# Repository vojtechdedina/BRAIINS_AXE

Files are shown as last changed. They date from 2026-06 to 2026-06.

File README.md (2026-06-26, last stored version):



**DoubleQ Rev2.2 **

Alternative PCB design to fit another cooler for an open PCB. 



Highlights in comparison to the "standard" NerdOCTAXE:
- runs far more silent
- lower temps on asics and buck
- open PCB-design

The NerdOCTAXEγ runs with a modified version of the AxeOS: [ESP-Miner-NerdQAxe+](https://github.com/shufps/ESP-Miner-NerdQAxePlus) (Releases for NerdOCTAXE-Gamma)

-------------------------------

# Build

**DISCLAIMER:** This device is an *highly advanced* build and partly WIP. To get 8 Asics and the voltage regulator soldered properly *can* be very hard and frustrating if you are not used to soldering Asics or soldering in general. Using that amount of power, this device isn't a toy and you should know what you are doing - stay safe! Also this device is not intended or designed to run overclocked.

**PCB:** For example with the JLC Plugin for Kicad you can export the files out of Kicad to order directly from JLCPCB or any other PCB-Manufacturer. I tested my prototype with 1oz on inner and outer layers... working nice :) If anyone is testing or 2/1oz please let me know of the results you are seeing!

**BOM:** You can directly upload the .csv in this repo to Digikey. You will have to order the Lilygo T-Display S3 and the XT60PW-M seperately 

**HEATSINKS:** For this build I used two Thermalright AXP90-X53. For cooling the CSDs I "tinkered" on a custom heatsink with a 150x10mm aluminum rod and some fins, which I cut off another heatsink :) But its possible to just use 4x smaller heatsink directly on the CSDs



Misc
====
If you like this project and want to support future work, feel free to donate to:
**`bc1q0ctaxeha3lpsaaz7kpjulflw2d9p66fhkp48dk`**

or related projects without which this project would not have been possible for me:

[Nerdaxe](https://github.com/BitMaker-hub/NerdAxeUltra)

[NerdQAxe+](https://github.com/shufps/qaxe)

[OSMU](https://osmu.wiki/)

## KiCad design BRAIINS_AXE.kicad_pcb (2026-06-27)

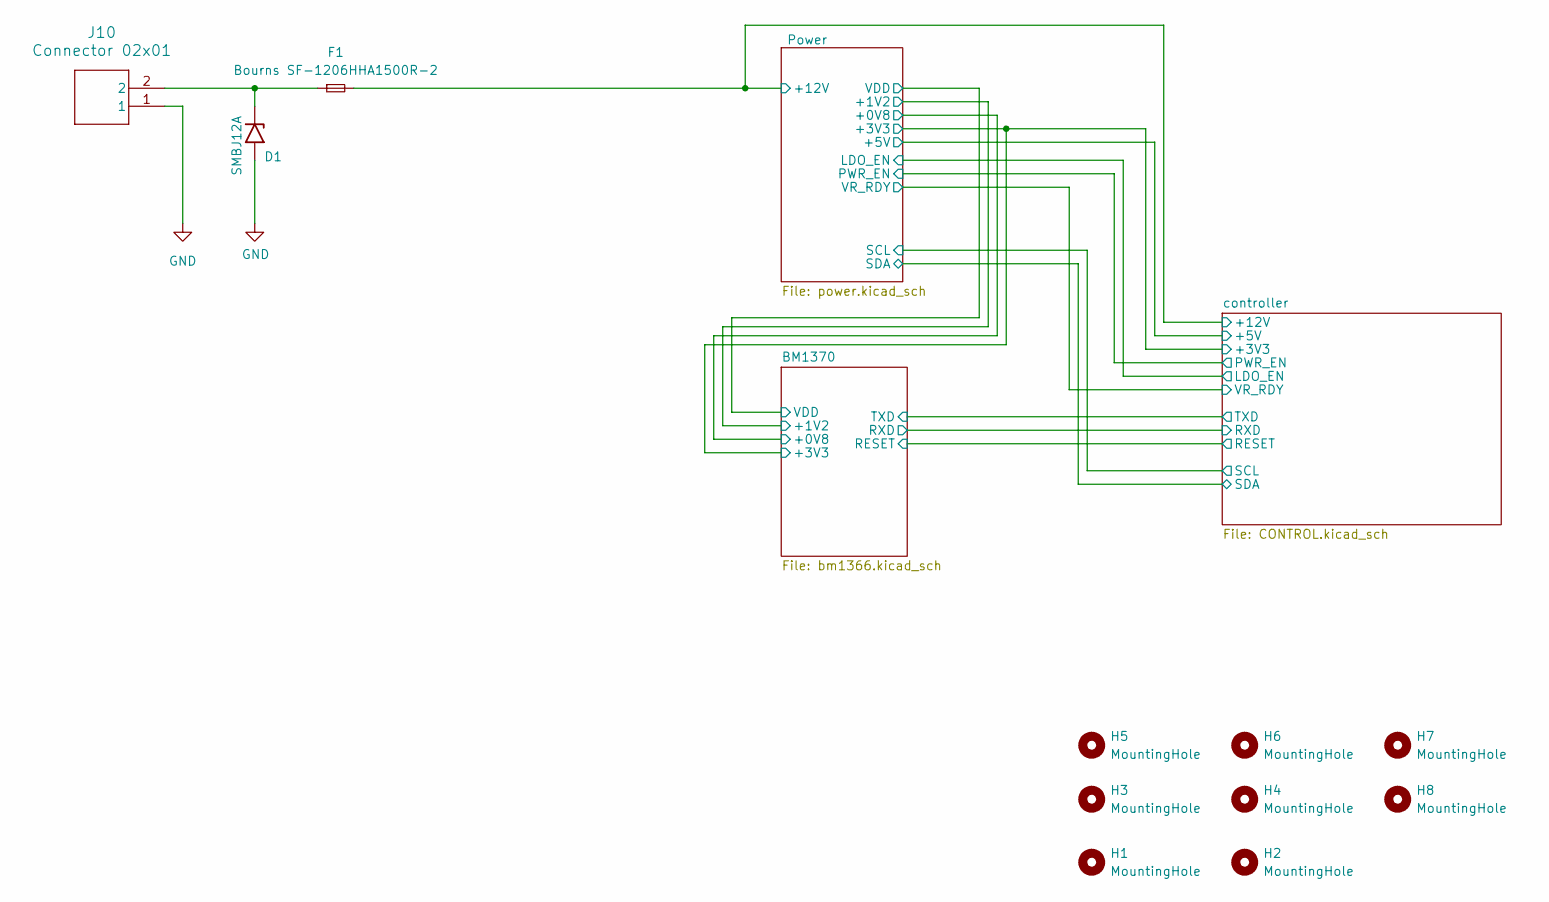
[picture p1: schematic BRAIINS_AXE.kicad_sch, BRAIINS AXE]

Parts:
D1: SMBJ12A; D_SMB
F1: Bourns SF-1206HHA1500R-2; Fuse_1210_3225Metric
H1, H2, H3, H4, H5, H6, H7, H8: MountingHole; MountingHole_3.2mm_M3_Pad_Via
J10: Connector 02x01; AMASS_XT60PW-M_1x02_P7.20mm_Horizontal

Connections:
+12V: F1.2; also elsewhere on the board
GND: D1.2 (A2), J10.1; also elsewhere on the board
unnamed: D1.1 (A1), F1.1, J10.2

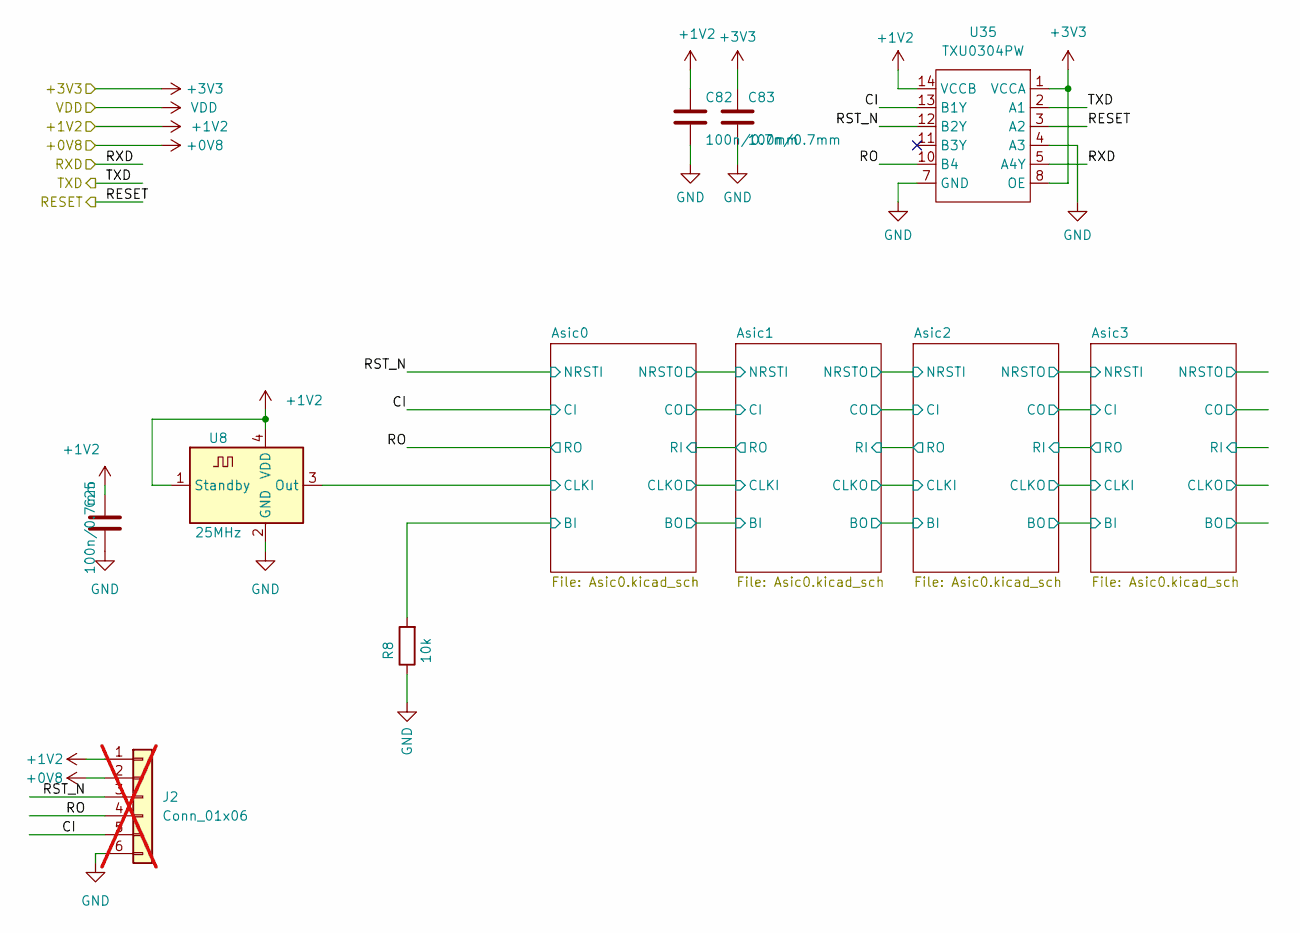
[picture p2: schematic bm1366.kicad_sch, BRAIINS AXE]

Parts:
C25, C82, C83: 100n/0.7mm; C_0805_2012Metric
J2: Conn_01x06; PinHeader_1x06_P1.27mm_Vertical; not fitted
R8: 10k; R_0805_2012Metric
U8: 25MHz; Oscillator_SMD_EuroQuartz_XO32-4Pin_3.2x2.5mm
U35: TXU0304PW; TSSOP-14-1EP_4.4x5mm_P0.65mm

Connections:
+0V8: J2.2; also elsewhere on the board
+1V2: C25.1, C82.1, J2.1, U8.1 (Standby), U8.4 (VDD), U35.14 (VCCB); also elsewhere on the board
+3V3: C83.1, U35.1 (VCCA), U35.8 (OE); also elsewhere on the board
/BM1370/Asic0/BI: R8.2; also elsewhere on the board
/BM1370/Asic0/CLKI: U8.3 (Out); also elsewhere on the board
/BM1370/CI: J2.5, U35.13 (B1Y); also elsewhere on the board
/BM1370/RESET: U35.3 (A2); also elsewhere on the board
/BM1370/RO: J2.4, U35.10 (B4); also elsewhere on the board
/BM1370/RST_N: J2.3, U35.12 (B2Y); also elsewhere on the board
/BM1370/RXD: U35.5 (A4Y); also elsewhere on the board
/BM1370/TXD: U35.2 (A1); also elsewhere on the board
GND: C25.2, C82.2, C83.2, J2.6, R8.1, U8.2 (GND), U35.4 (A3), U35.7 (GND); also elsewhere on the board

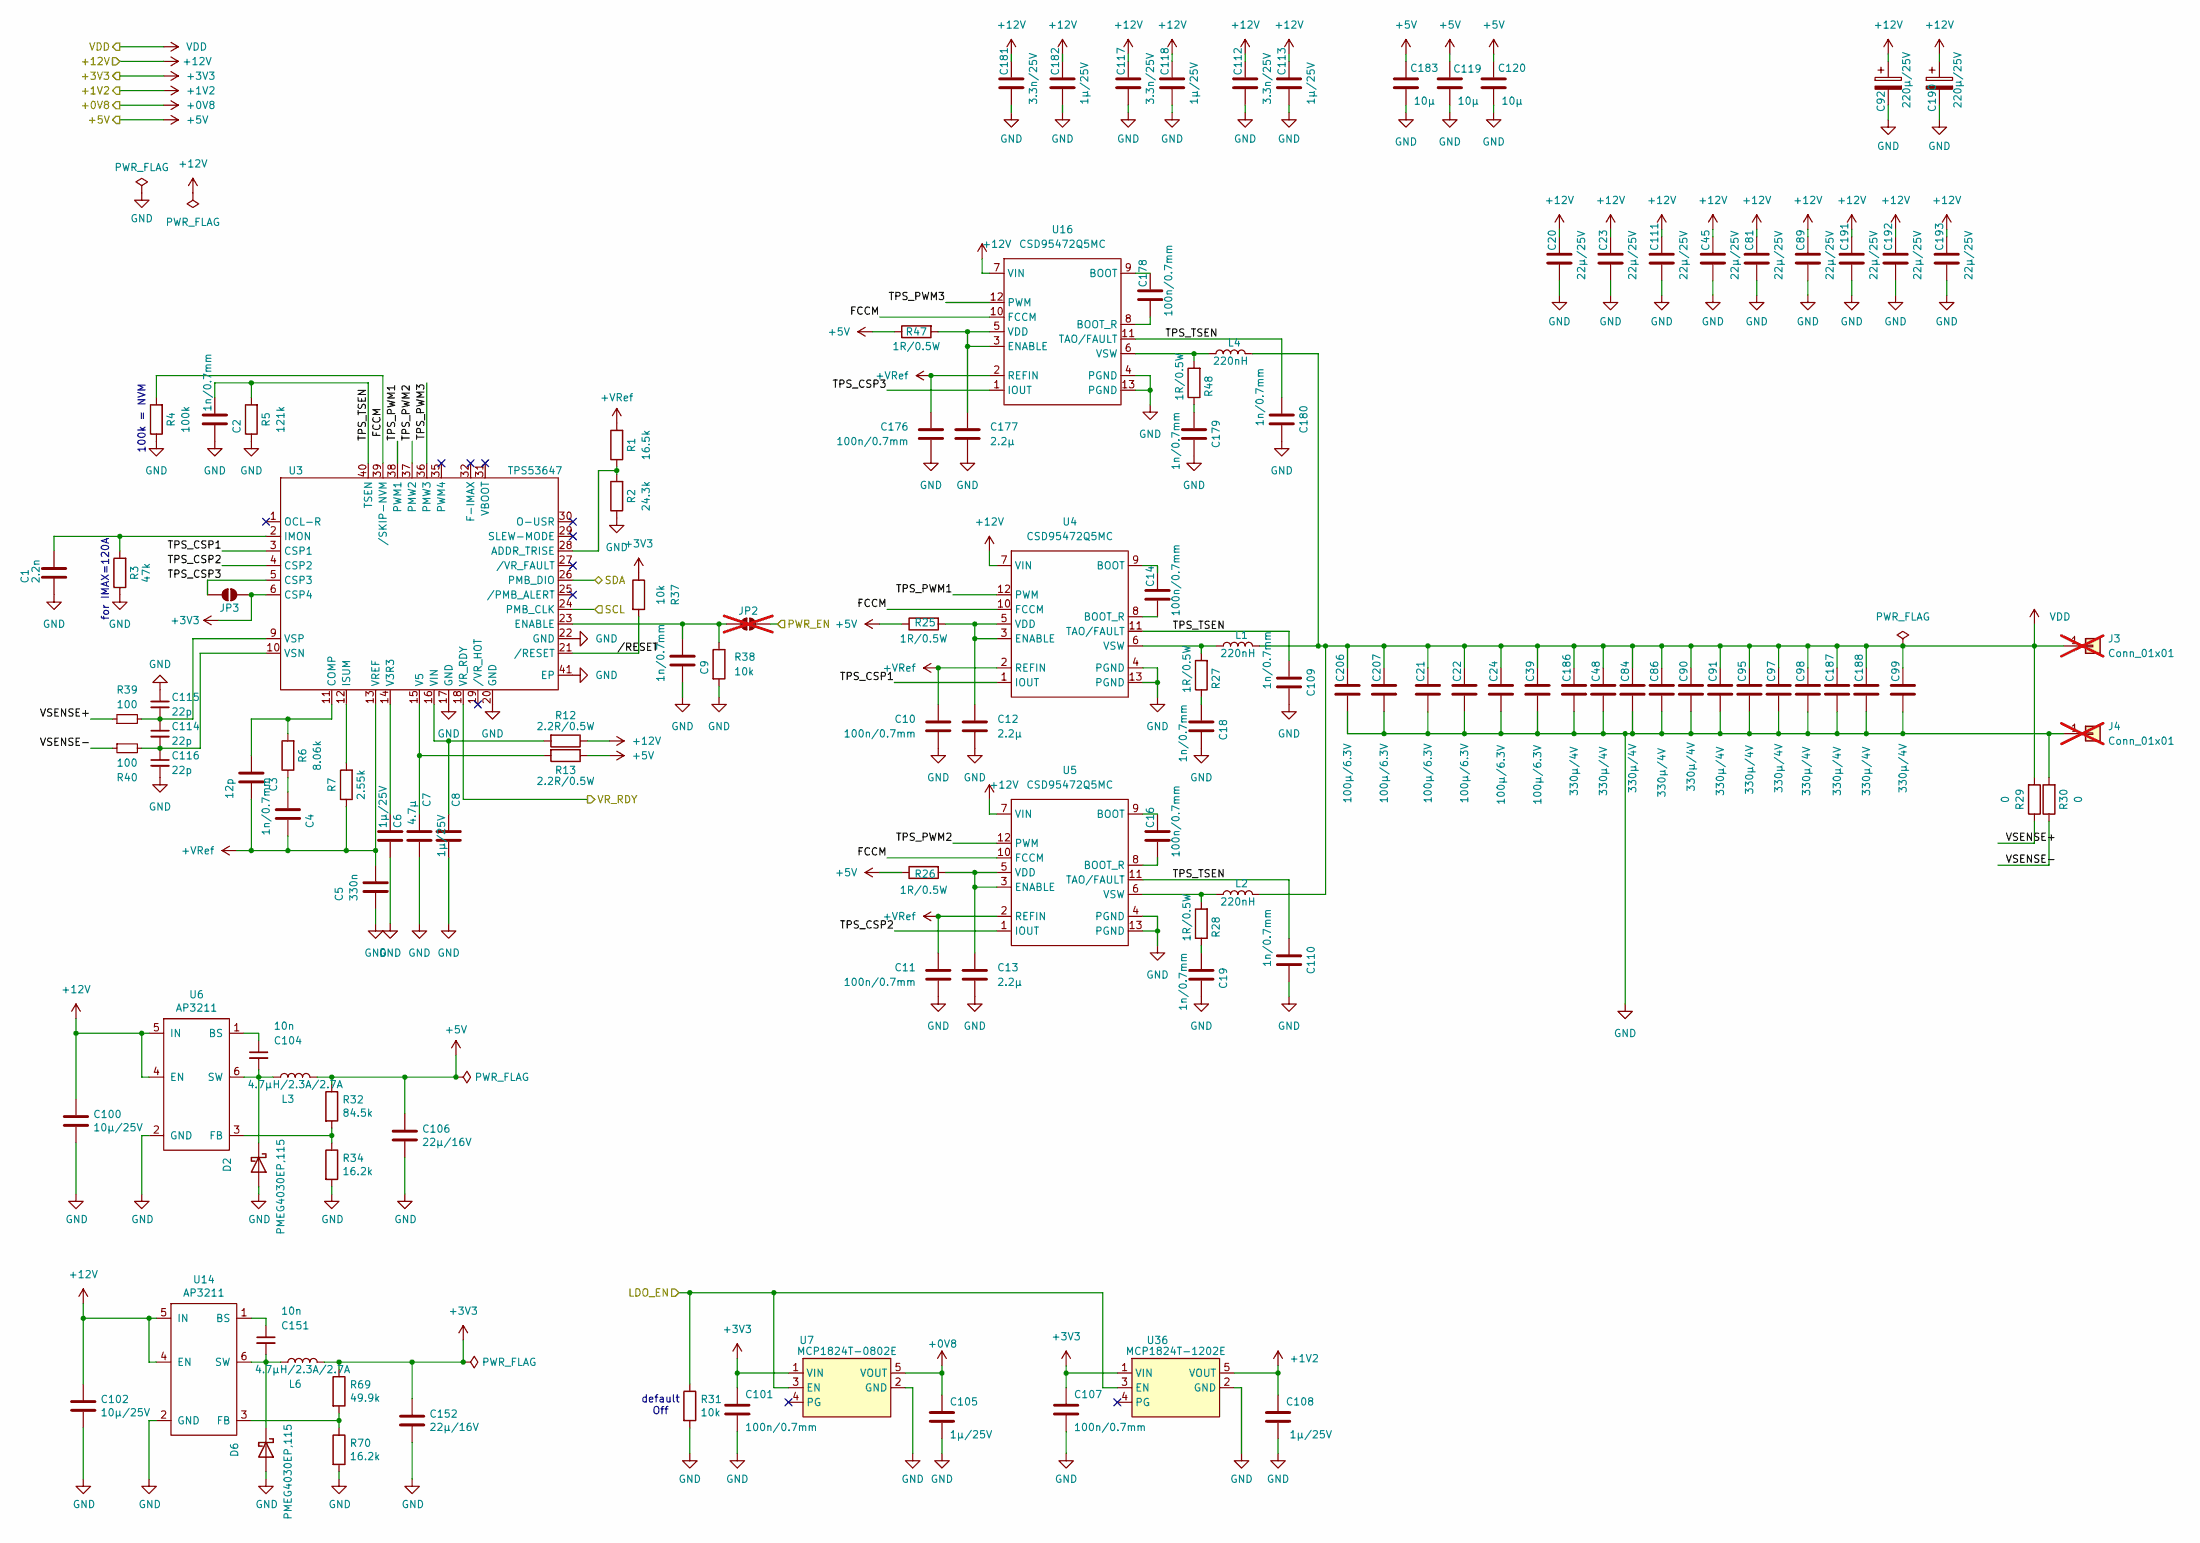
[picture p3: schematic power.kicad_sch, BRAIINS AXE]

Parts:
C1: 2.2n; C_0603_1608Metric
C2, C4, C9: 1n/0.7mm; C_0603_1608Metric
C3: 12p; C_0603_1608Metric
C5: 330n; C_0603_1608Metric
C6, C8, C113, C118, C182: 1µ/25V; C_0603_1608Metric
C7: 4.7µ; C_0603_1608Metric
C10, C11, C14, C16, C176, C178: 100n/0.7mm; C_0603_1608Metric
C12, C13, C177: 2.2µ; C_0603_1608Metric
C18, C19, C109, C110, C179, C180: 1n/0.7mm; C_0805_2012Metric
C20, C23, C45, C81, C89, C111, C191, C192, C193: 22µ/25V; C_1210_3225Metric
C21, C22, C24, C39, C206, C207: 100µ/6.3V; C_1210_3225Metric
C48, C84, C86, C90, C91, C95, C97, C98, C99, C186, C187, C188: 330µ/4V; C_1210_3225Metric
C92, C190: 220µ/25V; CP_Elec_8x10
C100, C102: 10µ/25V; C_0805_2012Metric
C101, C107: 100n/0.7mm; C_0805_2012Metric
C104, C151: 10n; C_0805_2012Metric
C105, C108: 1µ/25V; C_0805_2012Metric
C106, C152: 22µ/16V; C_1206_3216Metric
C112, C117, C181: 3.3n/25V; C_0603_1608Metric
C114, C115, C116: 22p; C_0603_1608Metric
C119, C120, C183: 10µ; C_0805_2012Metric
D2, D6: PMEG4030EP,115; D_SOD-128
J3, J4: Conn_01x01; Wuerth_REDCUBE-THR_WP-THRBU_74650194_THR; not fitted
JP2: SolderJumper_2_Open; SolderJumper-2_P1.3mm_Open_RoundedPad1.0x1.5mm; not fitted
JP3: SolderJumper_2_Open; SolderJumper-2_P1.3mm_Open_RoundedPad1.0x1.5mm
L1, L2, L4: 220nH; IFLR-4031GC-01-8x10
L3, L6: 4.7µH/2.3A/2.7A; L_Taiyo-Yuden_NR-50xx
R1: 16.5k; R_0603_1608Metric
R2: 24.3k; R_0603_1608Metric
R3: 47k; R_0603_1608Metric
R4: 100k; R_0603_1608Metric
R5: 121k; R_0603_1608Metric
R6: 8.06k; R_0603_1608Metric
R7: 2.55k; R_0603_1608Metric
R12, R13: 2.2R/0.5W; R_0805_2012Metric
R25, R26, R27, R28, R47, R48: 1R/0.5W; R_0805_2012Metric
R29, R30: 0; R_0805_2012Metric
R31: 10k; R_0805_2012Metric
R32: 84.5k; R_0603_1608Metric
R34, R70: 16.2k; R_0603_1608Metric
R37, R38: 10k; R_0603_1608Metric
R39, R40: 100; R_0603_1608Metric
R69: 49.9k; R_0603_1608Metric
U3: TPS53647; Texas_RHA0040B_VQFN-40-1EP_6x6mm_P0.5mm_EP4.15x4.15mm_Therm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
U4, U5, U16: CSD95472Q5MC; CSD95472-SON-5x6
U6, U14: AP3211; SOT-23-6
U7: MCP1824T-0802E; SOT-23-5
U36: MCP1824T-1202E; SOT-23-5

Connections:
+0V8: C105.1, U7.5 (VOUT); also elsewhere on the board
+1V2: C108.1, U36.5 (VOUT); also elsewhere on the board
+3V3: C101.1, C107.1, C152.1, JP3.2 (B), L6.2, R37.1, R69.1, U3.6 (CSP4), U7.1 (VIN), U36.1 (VIN); also elsewhere on the board
+5V: C106.1, C119.1, C120.1, C183.1, L3.2, R13.1, R25.1, R26.1, R32.1, R47.1
+12V: C20.1, C23.1, C45.1, C81.1, C89.1, C92.1, C100.1, C102.1, C111.1, C112.1, C113.1, C117.1, C118.1, C181.1, C182.1, C190.1, C191.1, C192.1, C193.1, R12.1, U4.7 (VIN), U5.7 (VIN), U6.4 (EN), U6.5 (IN), U14.4 (EN), U14.5 (IN), U16.7 (VIN); also elsewhere on the board
+VRef: C3.2, C4.2, C5.1, C10.1, C11.1, C176.1, R1.2, R7.1, U3.13 (VREF), U4.2 (REFIN), U5.2 (REFIN), U16.2 (REFIN)
/Power/FCCM: R4.2, U3.39 (/SKIP-NVM), U4.10 (FCCM), U5.10 (FCCM), U16.10 (FCCM)
/Power/LDO_EN: R31.1, U7.3 (EN), U36.3 (EN); also elsewhere on the board
/Power/PWR_EN: JP2.2 (B); also elsewhere on the board
/Power/TPS_CSP1: U3.3 (CSP1), U4.1 (IOUT)
/Power/TPS_CSP2: U3.4 (CSP2), U5.1 (IOUT)
/Power/TPS_CSP3: JP3.1 (A), U3.5 (CSP3), U16.1 (IOUT)
/Power/TPS_PWM1: U3.38 (PWM1), U4.12 (PWM)
/Power/TPS_PWM2: U3.37 (PMW2), U5.12 (PWM)
/Power/TPS_PWM3: U3.36 (PMW3), U16.12 (PWM)
/Power/TPS_TSEN: C2.1, C109.1, C110.1, C180.1, R5.2, U3.40 (TSEN), U4.11 (TAO/FAULT), U5.11 (TAO/FAULT), U16.11 (TAO/FAULT)
/Power/VR_RDY: U3.18 (VR_RDY); also elsewhere on the board
/Power/VSENSE+: R29.1, R39.1
/Power/VSENSE-: R30.1, R40.1
/Power//RESET: R37.2, U3.21 (/RESET)
/controller/SCL: U3.24 (PMB_CLK); also elsewhere on the board
/controller/SDA: U3.26 (PMB_DIO); also elsewhere on the board
GND: C1.2, C2.2, C5.2, C6.2, C7.1, C8.1, C9.2, C10.2, C11.2, C12.2, C13.2, C18.2, C19.2, C20.2, C21.2, C22.2, C23.2, C24.2, C39.2, C45.2, C48.2, C81.2, C84.2, C86.2, C89.2, C90.2, C91.2, C92.2, C95.2, C97.2, C98.2, C99.2, C100.2, C101.2, C102.2, C105.2, C106.2, C107.2, C108.2, C109.2, C110.2, C111.2, C112.2, C113.2, C115.1, C116.2, C117.2, C118.2, C119.2, C120.2, C152.2, C176.2, C177.2, C179.2, C180.2, C181.2, C182.2, C183.2, C186.2, C187.2, C188.2, C190.2, C191.2, C192.2, C193.2, C206.2, C207.2, D2.2 (A), D6.2 (A), J4.1, R2.1, R3.1, R4.1, R5.1, R30.2, R31.2, R34.2, R38.2, R70.2, U3.17 (GND), U3.20 (GND), U3.22 (GND), U3.41 (EP), U4.4 (PGND), U4.13 (PGND), U5.4 (PGND), U5.13 (PGND), U6.2 (GND), U7.2 (GND), U14.2 (GND), U16.4 (PGND), U16.13 (PGND), U36.2 (GND); also elsewhere on the board
unnamed: C4.1, R6.1
unnamed: C18.1, R27.1
unnamed: C19.1, R28.1
unnamed: C179.1, R48.1
unnamed: C104.2, D2.1 (K), L3.1, U6.6 (SW)
unnamed: C151.2, D6.1 (K), L6.1, U14.6 (SW)
unnamed: C9.1, JP2.1 (A), R38.1, U3.23 (ENABLE)
unnamed: R1.1, R2.2, U3.28 (ADDR_TRISE)
unnamed: C3.1, R6.2, U3.11 (COMP)
unnamed: C1.1, R3.2, U3.2 (IMON)
unnamed: R7.2, U3.12 (ISUM)
unnamed: C6.1, U3.14 (V3R3)
unnamed: C7.2, R13.2, U3.15 (V5)
unnamed: C8.2, R12.2, U3.16 (VIN)
unnamed: C114.2, C116.1, R40.2, U3.10 (VSN)
unnamed: C114.1, C115.2, R39.2, U3.9 (VSP)
unnamed: C14.1, U4.9 (BOOT)
unnamed: C14.2, U4.8 (BOOT_R)
unnamed: C12.1, R25.2, U4.3 (ENABLE), U4.5 (VDD)
unnamed: L1.1, R27.2, U4.6 (VSW)
unnamed: C16.1, U5.9 (BOOT)
unnamed: C16.2, U5.8 (BOOT_R)
unnamed: C13.1, R26.2, U5.3 (ENABLE), U5.5 (VDD)
unnamed: L2.1, R28.2, U5.6 (VSW)
unnamed: C104.1, U6.1 (BS)
unnamed: R32.2, R34.1, U6.3 (FB)
unnamed: C151.1, U14.1 (BS)
unnamed: R69.2, R70.1, U14.3 (FB)
unnamed: C178.1, U16.9 (BOOT)
unnamed: C178.2, U16.8 (BOOT_R)
unnamed: C177.1, R47.2, U16.3 (ENABLE), U16.5 (VDD)
unnamed: L4.1, R48.2, U16.6 (VSW)
VDD: C21.1, C22.1, C24.1, C39.1, C48.1, C84.1, C86.1, C90.1, C91.1, C95.1, C97.1, C98.1, C99.1, C186.1, C187.1, C188.1, C206.1, C207.1, J3.1, L1.2, L2.2, L4.2, R29.2; also elsewhere on the board

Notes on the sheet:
default Off
for IMAX=120A
100k = NVM

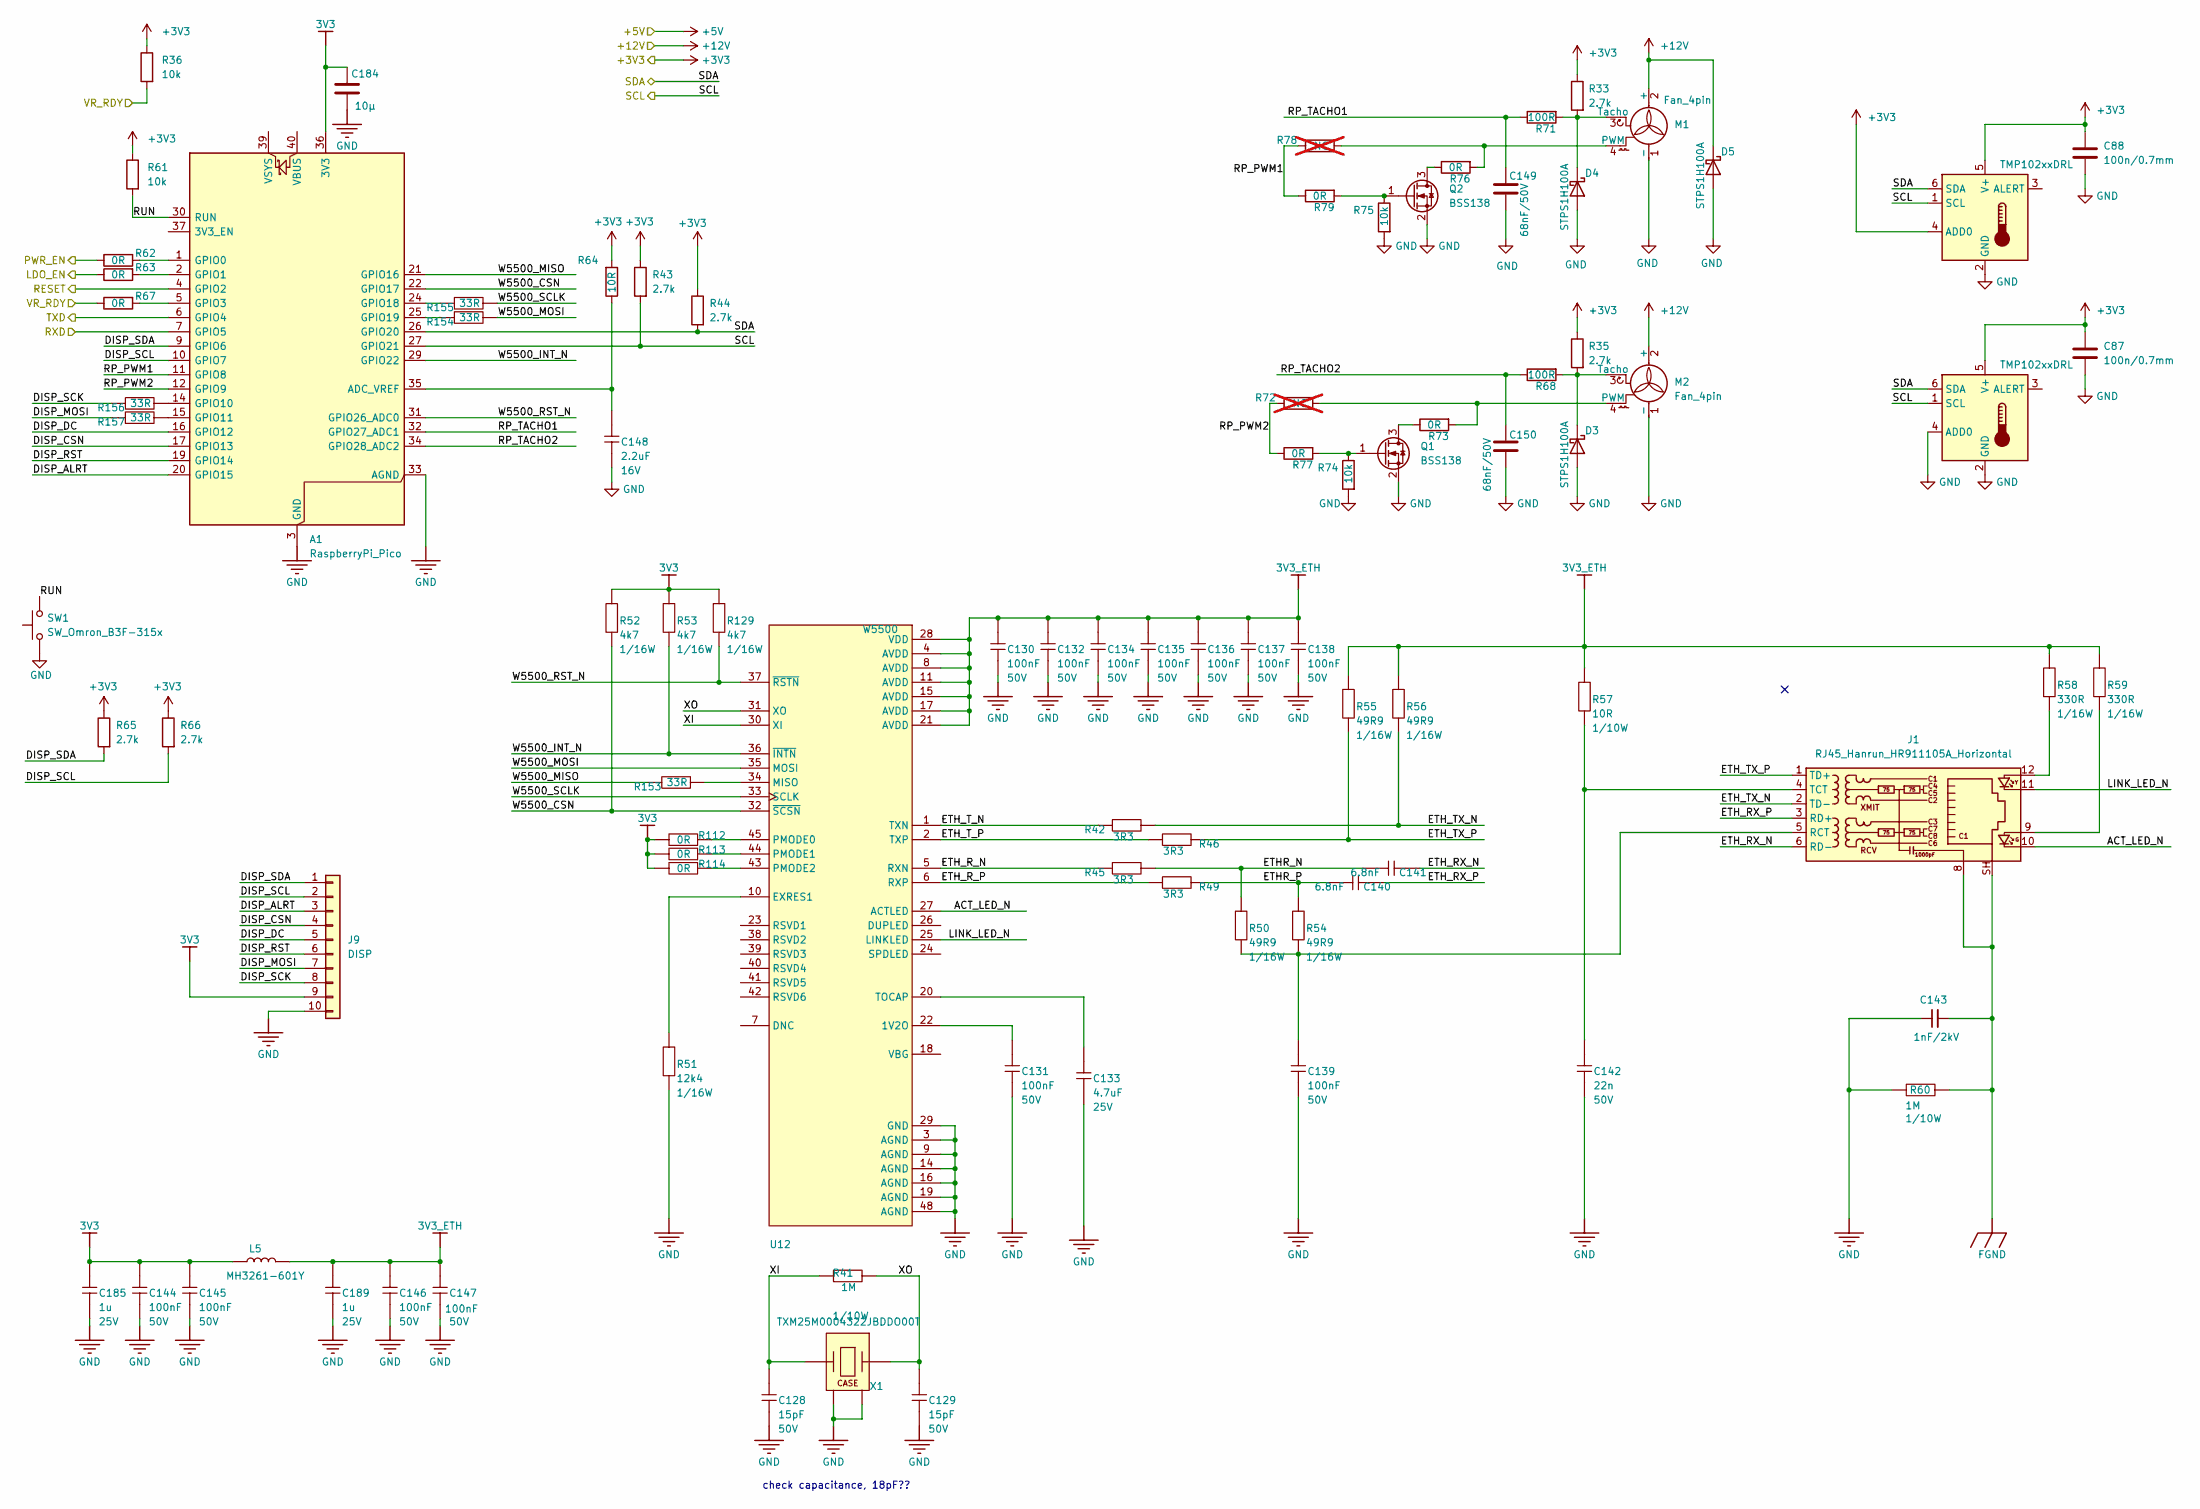
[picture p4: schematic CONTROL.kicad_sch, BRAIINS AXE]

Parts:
A1: RaspberryPi_Pico; RaspberryPi_Pico_Common_Unspecified
C87, C88: 100n/0.7mm; C_0603_1608Metric
C128, C129: 15pF; C_0603_1608Metric; VOLTAGE_RATING 50V; TOLERANCE 1%; PART_TYPE Capacitor
C130, C131, C132, C134, C135, C136, C137, C138, C139, C144, C145, C146, C147: 100nF; C_0603_1608Metric; VOLTAGE_RATING 50V; TOLERANCE 10%; PART_TYPE Capacitor
C133: 4.7uF; C_0603_1608Metric; VOLTAGE_RATING 25V; TOLERANCE 10%; PART_TYPE Capacitor
C140, C141: 6.8nF; C_0603_1608Metric; VOLTAGE_RATING 50V; TOLERANCE 10%; PART_TYPE Capacitor
C142: 22n; C_0603_1608Metric; VOLTAGE_RATING 50V; TOLERANCE 10%; PART_TYPE Capacitor
C143: 1nF/2kV; C_1206_3216Metric
C148: 2.2uF; C_0603_1608Metric; VOLTAGE_RATING 16V; TOLERANCE 10%; PART_TYPE Capacitor
C149, C150: 68nF/50V; C_0603_1608Metric
C184: 10µ; C_0805_2012Metric
C185, C189: 1u; C_0603_1608Metric; VOLTAGE_RATING 25V; TOLERANCE 10%; PART_TYPE Capacitor
D3, D4, D5: STPS1H100A; D_SMA
J1: RJ45_Hanrun_HR911105A_Horizontal
J9: DISP; PinHeader_1x10_P2.54mm_Vertical
L5: MH3261-601Y; L_1206_3216Metric; PART_TYPE Filter
M1, M2: Fan_4pin; FanPinHeader_1x04_P2.54mm_Vertical
Q1, Q2: BSS138; SOT-23
R33, R35, R43, R44, R65, R66: 2.7k; R_0603_1608Metric
R36, R61, R74, R75: 10k; R_0603_1608Metric
R41, R60: 1M; R_0603_1608Metric; TOLERANCE 1%; PART_TYPE Resistor
R42, R45, R46, R49: 3R3; R_0603_1608Metric; TOLERANCE 1%; PART_TYPE Resistor
R50, R54, R55, R56: 49R9; R_0603_1608Metric; TOLERANCE 1%; PART_TYPE Resistor
R51: 12k4; R_0603_1608Metric; TOLERANCE 1%; PART_TYPE Resistor
R52, R53, R129: 4k7; R_0603_1608Metric; TOLERANCE 1%; PART_TYPE Resistor
R57: 10R; R_0603_1608Metric; TOLERANCE 1%; PART_TYPE Resistor
R58, R59: 330R; R_0603_1608Metric; TOLERANCE 1%; PART_TYPE Resistor
R62, R63, R67, R73, R76, R77, R79: 0R; R_0603_1608Metric
R64: 10R; R_0603_1608Metric
R68, R71: 100R; R_0603_1608Metric
R72, R78: NC; R_0603_1608Metric; not fitted
R112, R113, R114: 0R; R_0603_1608Metric; TOLERANCE 1%; PART_TYPE Resistor
R153, R154, R155, R156, R157: 33R; R_0603_1608Metric; TOLERANCE 1%; PART_TYPE Resistor
SW1: SW_Omron_B3F-315x; SW_SPST_Omron_B3F-315x_Angled
U1, U13: TMP102xxDRL; SOT-563
U12: W5500; LQFP-48_7x7mm_P0.5mm; PART_TYPE IC; LCSC C32843
X1: TXM25M0004322JBDDO00T; Crystal_SMD_3225-4Pin_3.2x2.5mm; PART_TYPE Crystal; LCSC C362473

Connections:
3V3: A1.36 (3V3), C144.1, C145.1, C184.1, C185.1, J9.9, L5.1, R52.2, R53.2, R112.2, R113.2, R114.2, R129.2
3V3_ETH: C130.1, C132.1, C134.1, C135.1, C136.1, C137.1, C138.1, C146.1, C147.1, C189.1, L5.2, R55.2, R56.2, R57.2, R58.2, R59.2, U12.4 (AVDD), U12.8 (AVDD), U12.11 (AVDD), U12.15 (AVDD), U12.17 (AVDD), U12.21 (AVDD), U12.28 (VDD)
+3V3: C87.1, C88.1, R33.1, R35.1, R36.1, R43.1, R44.1, R61.1, R64.2, R65.1, R66.1, U1.5 (V+), U13.4 (ADD0), U13.5 (V+); also elsewhere on the board
+12V: D5.1 (K), M1.2 (+), M2.2 (+); also elsewhere on the board
/BM1370/RESET: A1.4 (GPIO2); also elsewhere on the board
/BM1370/RXD: A1.7 (GPIO5); also elsewhere on the board
/BM1370/TXD: A1.6 (GPIO4); also elsewhere on the board
/Power/LDO_EN: R63.1; also elsewhere on the board
/Power/PWR_EN: R62.1; also elsewhere on the board
/Power/VR_RDY: R36.2, R67.1; also elsewhere on the board
/controller/ACT_LED_N: J1.10, U12.27 (ACTLED)
/controller/DISP_ALRT: A1.20 (GPIO15), J9.3
/controller/DISP_CSN: A1.17 (GPIO13), J9.4
/controller/DISP_DC: A1.16 (GPIO12), J9.5
/controller/DISP_MOSI: J9.7, R157.1
/controller/DISP_RST: A1.19 (GPIO14), J9.6
/controller/DISP_SCK: J9.8, R156.1
/controller/DISP_SCL: A1.10 (GPIO7), J9.2, R66.2
/controller/DISP_SDA: A1.9 (GPIO6), J9.1, R65.2
/controller/ETHR_N: C141.1, R45.2, R50.2
/controller/ETHR_P: C140.1, R49.2, R54.2
/controller/ETH_RX_N: C141.2, J1.6 (RD-)
/controller/ETH_RX_P: C140.2, J1.3 (RD+)
/controller/ETH_R_N: R45.1, U12.5 (RXN)
/controller/ETH_R_P: R49.1, U12.6 (RXP)
/controller/ETH_TX_N: J1.2 (TD-), R42.2, R56.1
/controller/ETH_TX_P: J1.1 (TD+), R46.2, R55.1
/controller/ETH_T_N: R42.1, U12.1 (TXN)
/controller/ETH_T_P: R46.1, U12.2 (TXP)
/controller/LINK_LED_N: J1.11, U12.25 (LINKLED)
/controller/RP_PWM1: A1.11 (GPIO8), R78.1, R79.1
/controller/RP_PWM2: A1.12 (GPIO9), R72.1, R77.1
/controller/RP_TACHO1: A1.32 (GPIO27_ADC1), C149.1, R71.1
/controller/RP_TACHO2: A1.34 (GPIO28_ADC2), C150.1, R68.1
/controller/RUN: A1.30 (RUN), R61.2, SW1.2
/controller/SCL: A1.27 (GPIO21), R43.2, U1.1 (SCL), U13.1 (SCL); also elsewhere on the board
/controller/SDA: A1.26 (GPIO20), R44.2, U1.6 (SDA), U13.6 (SDA); also elsewhere on the board
/controller/W5500_CSN: A1.22 (GPIO17), R52.1, U12.32 (~SCSN)
/controller/W5500_INT_N: A1.29 (GPIO22), R53.1, U12.36 (~INTN)
/controller/W5500_MISO: A1.21 (GPIO16), R153.1
/controller/W5500_MOSI: R154.2, U12.35 (MOSI)
/controller/W5500_RST_N: A1.31 (GPIO26_ADC0), R129.1, U12.37 (~RSTN)
/controller/W5500_SCLK: R155.2, U12.33 (SCLK)
/controller/XI: C128.1, R41.1, U12.30 (XI), X1.1 (X1)
/controller/XO: C129.1, R41.2, U12.31 (XO), X1.3 (X2)
FGND: C143.2, J1.8, J1.SH, R60.2
GND: A1.3 (GND), A1.8 (GND), A1.13 (GND), A1.18 (GND), A1.23 (GND), A1.28 (GND), A1.33 (AGND), A1.38 (GND), C87.2, C88.2, C128.2, C129.2, C130.2, C131.2, C132.2, C133.2, C134.2, C135.2, C136.2, C137.2, C138.2, C139.2, C142.2, C143.1, C144.2, C145.2, C146.2, C147.2, C148.2, C149.2, C150.2, C184.2, C185.2, C189.2, D3.2 (A), D4.2 (A), D5.2 (A), J9.10, M1.1 (-), M2.1 (-), Q1.2 (S), Q2.2 (S), R51.1, R60.1, R74.2, R75.2, SW1.1, U1.2 (GND), U1.4 (ADD0), U12.3 (AGND), U12.9 (AGND), U12.14 (AGND), U12.16 (AGND), U12.19 (AGND), U12.29 (GND), U12.48 (AGND), U13.2 (GND), X1.2 (CASE), X1.4 (CASE); also elsewhere on the board
unnamed: A1.35 (ADC_VREF), C148.1, R64.1
unnamed: A1.1 (GPIO0), R62.2
unnamed: A1.2 (GPIO1), R63.2
unnamed: A1.5 (GPIO3), R67.2
unnamed: A1.14 (GPIO10), R156.2
unnamed: A1.15 (GPIO11), R157.2
unnamed: A1.24 (GPIO18), R155.1
unnamed: A1.25 (GPIO19), R154.1
unnamed: D3.1 (K), M2.3 (Tacho), R35.2, R68.2
unnamed: D4.1 (K), M1.3 (Tacho), R33.2, R71.2
unnamed: J1.9, R59.1
unnamed: J1.12, R58.1
unnamed: C139.1, J1.5 (RCT), R50.1, R54.1
unnamed: C142.1, J1.4 (TCT), R57.1
unnamed: M1.4 (PWM), R76.2, R78.2
unnamed: M2.4 (PWM), R72.2, R73.2
unnamed: Q1.3 (D), R73.1
unnamed: Q1.1 (G), R74.1, R77.2
unnamed: Q2.3 (D), R76.1
unnamed: Q2.1 (G), R75.1, R79.2
unnamed: C131.1, U12.22 (1V2O)
unnamed: R51.2, U12.10 (EXRES1)
unnamed: R153.2, U12.34 (MISO)
unnamed: R112.1, U12.45 (PMODE0)
unnamed: R113.1, U12.44 (PMODE1)
unnamed: R114.1, U12.43 (PMODE2)
unnamed: C133.1, U12.20 (TOCAP)

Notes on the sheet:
check capacitance, 18pF??

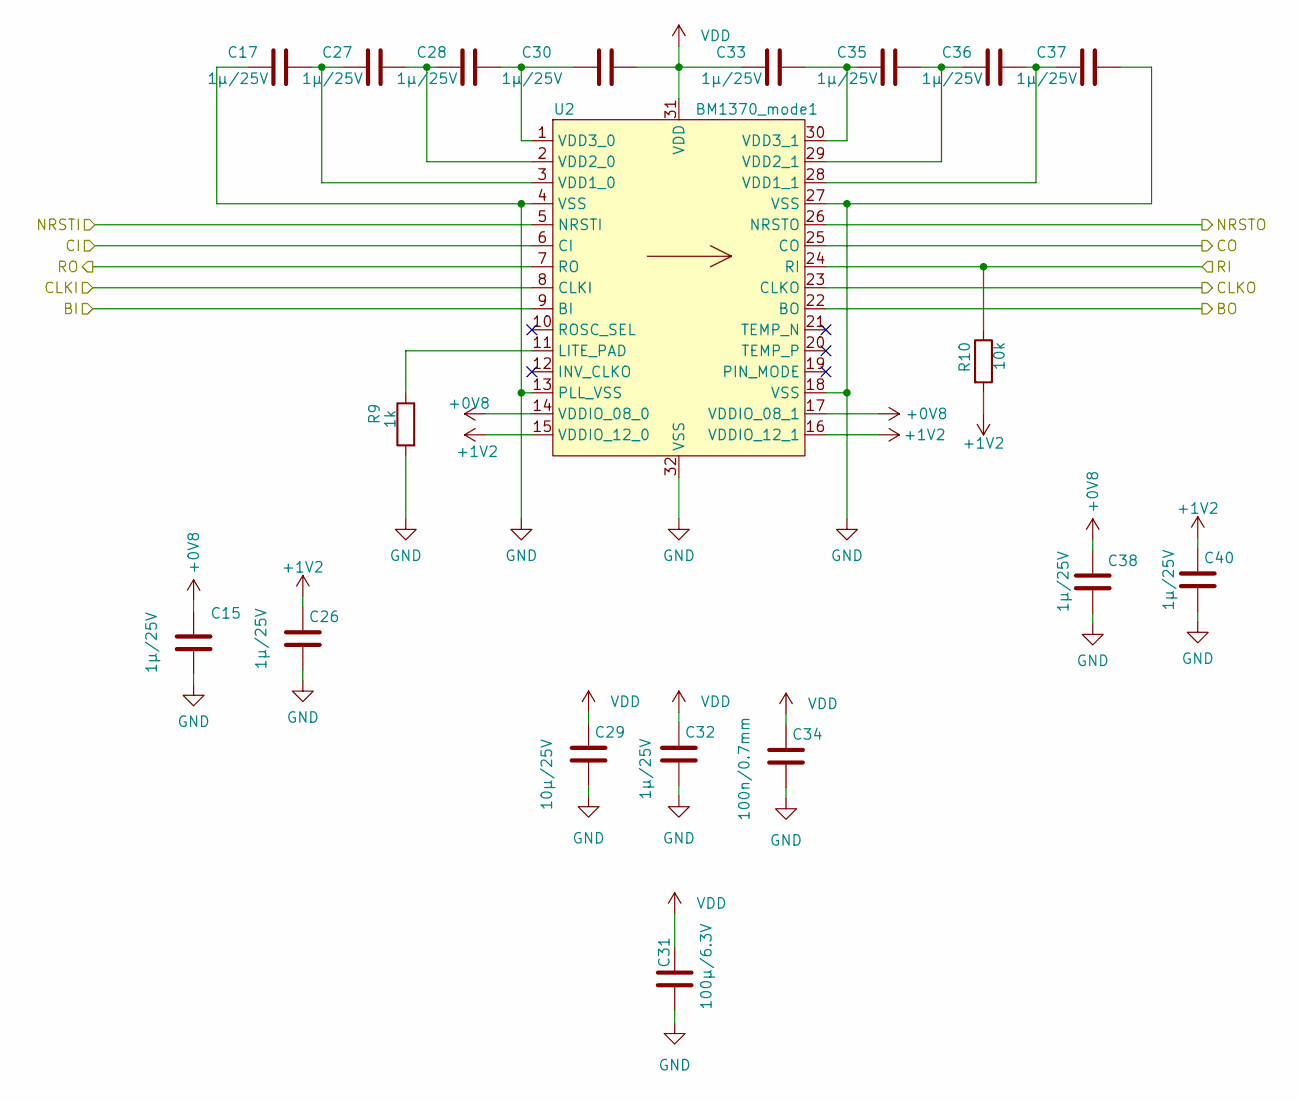
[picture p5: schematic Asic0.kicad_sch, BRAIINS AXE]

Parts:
C15, C17, C26, C27, C28, C30, C32, C33, C35, C36, C37, C38, C40: 1µ/25V; C_0805_2012Metric
C29: 10µ/25V; C_0805_2012Metric
C31: 100µ/6.3V; C_1210_3225Metric
C34: 100n/0.7mm; C_0805_2012Metric
R9: 1k; R_0805_2012Metric
R10: 10k; R_0805_2012Metric
U2: BM1370_mode1; BM1370

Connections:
+0V8: C15.2, C38.2, U2.14 (VDDIO_08_0), U2.17 (VDDIO_08_1); also elsewhere on the board
+1V2: C26.1, C40.1, R10.2, U2.15 (VDDIO_12_0), U2.16 (VDDIO_12_1); also elsewhere on the board
/BM1370/Asic0/BI: U2.9 (BI); also elsewhere on the board
/BM1370/Asic0/BO: U2.22 (BO); also elsewhere on the board
/BM1370/Asic0/CLKI: U2.8 (CLKI); also elsewhere on the board
/BM1370/Asic0/CLKO: U2.23 (CLKO); also elsewhere on the board
/BM1370/Asic0/CO: U2.25 (CO); also elsewhere on the board
/BM1370/Asic0/NRSTO: U2.26 (NRSTO); also elsewhere on the board
/BM1370/Asic0/RI: R10.1, U2.24 (RI); also elsewhere on the board
/BM1370/CI: U2.6 (CI); also elsewhere on the board
/BM1370/RO: U2.7 (RO); also elsewhere on the board
/BM1370/RST_N: U2.5 (NRSTI); also elsewhere on the board
GND: C15.1, C17.1, C26.2, C29.2, C31.2, C32.2, C34.2, C37.2, C38.1, C40.2, R9.2, U2.4 (VSS), U2.13 (PLL_VSS), U2.18 (VSS), U2.27 (VSS), U2.32 (VSS); also elsewhere on the board
unnamed: R9.1, U2.11 (LITE_PAD)
unnamed: C17.2, C27.1, U2.3 (VDD1_0)
unnamed: C36.2, C37.1, U2.28 (VDD1_1)
unnamed: C27.2, C28.1, U2.2 (VDD2_0)
unnamed: C35.2, C36.1, U2.29 (VDD2_1)
unnamed: C28.2, C30.1, U2.1 (VDD3_0)
unnamed: C33.2, C35.1, U2.30 (VDD3_1)
VDD: C29.1, C30.2, C31.1, C32.1, C33.1, C34.1, U2.31 (VDD); also elsewhere on the board

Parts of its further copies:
C41, C42, C43, C44, C46, C49, C51, C52, C54, C55, C56, C57, C58, C59, C60, C61, C62, C63, C65, C67, C68, C70, C71, C72, C73, C74, C75, C76, C77, C78, C79, C85, C94, C121, C123, C124, C125, C126, C127: 1µ/25V; C_0805_2012Metric
C47, C64, C80: 10µ/25V; C_0805_2012Metric
C50, C66, C93: 100µ/6.3V; C_1210_3225Metric
C53, C69, C122: 100n/0.7mm; C_0805_2012Metric
R11, R15, R17: 1k; R_0805_2012Metric
R14, R16, R18: 10k; R_0805_2012Metric
U9, U10, U11: BM1370_mode1; BM1370

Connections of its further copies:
+0V8: C41.2, C57.2, C59.2, C73.2, C75.2, C126.2, U9.14 (VDDIO_08_0), U9.17 (VDDIO_08_1), U10.14 (VDDIO_08_0), U10.17 (VDDIO_08_1), U11.14 (VDDIO_08_0), U11.17 (VDDIO_08_1); also elsewhere on the board
+1V2: C43.1, C58.1, C61.1, C74.1, C77.1, C127.1, R14.2, R16.2, R18.2, U9.15 (VDDIO_12_0), U9.16 (VDDIO_12_1), U10.15 (VDDIO_12_0), U10.16 (VDDIO_12_1), U11.15 (VDDIO_12_0), U11.16 (VDDIO_12_1); also elsewhere on the board
/BM1370/Asic0/BO: U9.9 (BI); also elsewhere on the board
/BM1370/Asic0/CLKO: U9.8 (CLKI); also elsewhere on the board
/BM1370/Asic0/CO: U9.6 (CI); also elsewhere on the board
/BM1370/Asic0/NRSTO: U9.5 (NRSTI); also elsewhere on the board
/BM1370/Asic0/RI: U9.7 (RO); also elsewhere on the board
/BM1370/Asic1/BO: U9.22 (BO), U10.9 (BI)
/BM1370/Asic1/CLKO: U9.23 (CLKO), U10.8 (CLKI)
/BM1370/Asic1/CO: U9.25 (CO), U10.6 (CI)
/BM1370/Asic1/NRSTO: U9.26 (NRSTO), U10.5 (NRSTI)
/BM1370/Asic1/RI: R14.1, U9.24 (RI), U10.7 (RO)
/BM1370/Asic2/BO: U10.22 (BO), U11.9 (BI)
/BM1370/Asic2/CLKO: U10.23 (CLKO), U11.8 (CLKI)
/BM1370/Asic2/CO: U10.25 (CO), U11.6 (CI)
/BM1370/Asic2/NRSTO: U10.26 (NRSTO), U11.5 (NRSTI)
/BM1370/Asic2/RI: R16.1, U10.24 (RI), U11.7 (RO)
/BM1370/Asic3/BO: U11.22 (BO)
/BM1370/Asic3/CLKO: U11.23 (CLKO)
/BM1370/Asic3/CO: U11.25 (CO)
/BM1370/Asic3/NRSTO: U11.26 (NRSTO)
/BM1370/Asic3/RI: R18.1, U11.24 (RI)
GND: C41.1, C42.1, C43.2, C47.2, C50.2, C51.2, C53.2, C56.2, C57.1, C58.2, C59.1, C60.1, C61.2, C64.2, C66.2, C67.2, C69.2, C72.2, C73.1, C74.2, C75.1, C76.1, C77.2, C80.2, C93.2, C94.2, C122.2, C125.2, C126.1, C127.2, R11.2, R15.2, R17.2, U9.4 (VSS), U9.13 (PLL_VSS), U9.18 (VSS), U9.27 (VSS), U9.32 (VSS), U10.4 (VSS), U10.13 (PLL_VSS), U10.18 (VSS), U10.27 (VSS), U10.32 (VSS), U11.4 (VSS), U11.13 (PLL_VSS), U11.18 (VSS), U11.27 (VSS), U11.32 (VSS); also elsewhere on the board
unnamed: R11.1, U9.11 (LITE_PAD)
unnamed: C42.2, C44.1, U9.3 (VDD1_0)
unnamed: C55.2, C56.1, U9.28 (VDD1_1)
unnamed: C44.2, C46.1, U9.2 (VDD2_0)
unnamed: C54.2, C55.1, U9.29 (VDD2_1)
unnamed: C46.2, C49.1, U9.1 (VDD3_0)
unnamed: C52.2, C54.1, U9.30 (VDD3_1)
unnamed: R15.1, U10.11 (LITE_PAD)
unnamed: C60.2, C62.1, U10.3 (VDD1_0)
unnamed: C71.2, C72.1, U10.28 (VDD1_1)
unnamed: C62.2, C63.1, U10.2 (VDD2_0)
unnamed: C70.2, C71.1, U10.29 (VDD2_1)
unnamed: C63.2, C65.1, U10.1 (VDD3_0)
unnamed: C68.2, C70.1, U10.30 (VDD3_1)
unnamed: R17.1, U11.11 (LITE_PAD)
unnamed: C76.2, C78.1, U11.3 (VDD1_0)
unnamed: C124.2, C125.1, U11.28 (VDD1_1)
unnamed: C78.2, C79.1, U11.2 (VDD2_0)
unnamed: C123.2, C124.1, U11.29 (VDD2_1)
unnamed: C79.2, C85.1, U11.1 (VDD3_0)
unnamed: C121.2, C123.1, U11.30 (VDD3_1)
VDD: C47.1, C49.2, C50.1, C51.1, C52.1, C53.1, C64.1, C65.2, C66.1, C67.1, C68.1, C69.1, C80.1, C85.2, C93.1, C94.1, C121.1, C122.1, U9.31 (VDD), U10.31 (VDD), U11.31 (VDD); also elsewhere on the board

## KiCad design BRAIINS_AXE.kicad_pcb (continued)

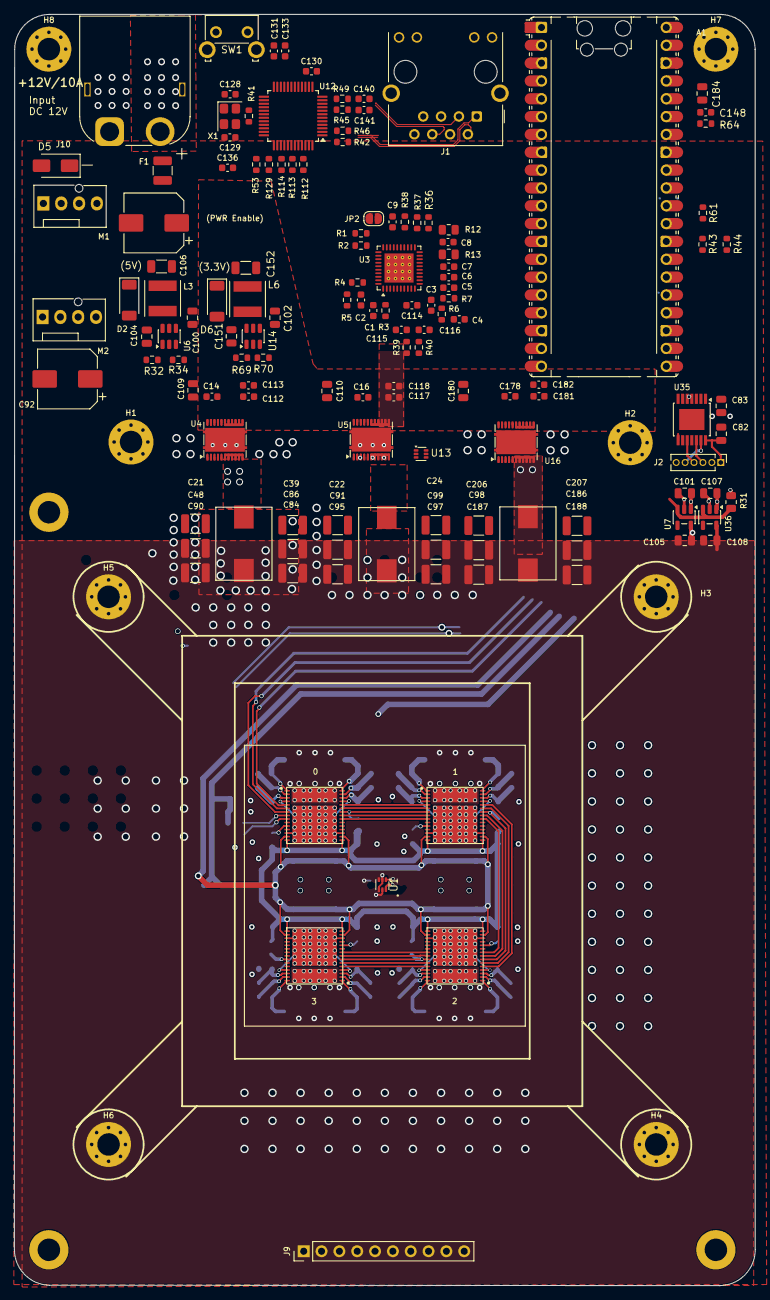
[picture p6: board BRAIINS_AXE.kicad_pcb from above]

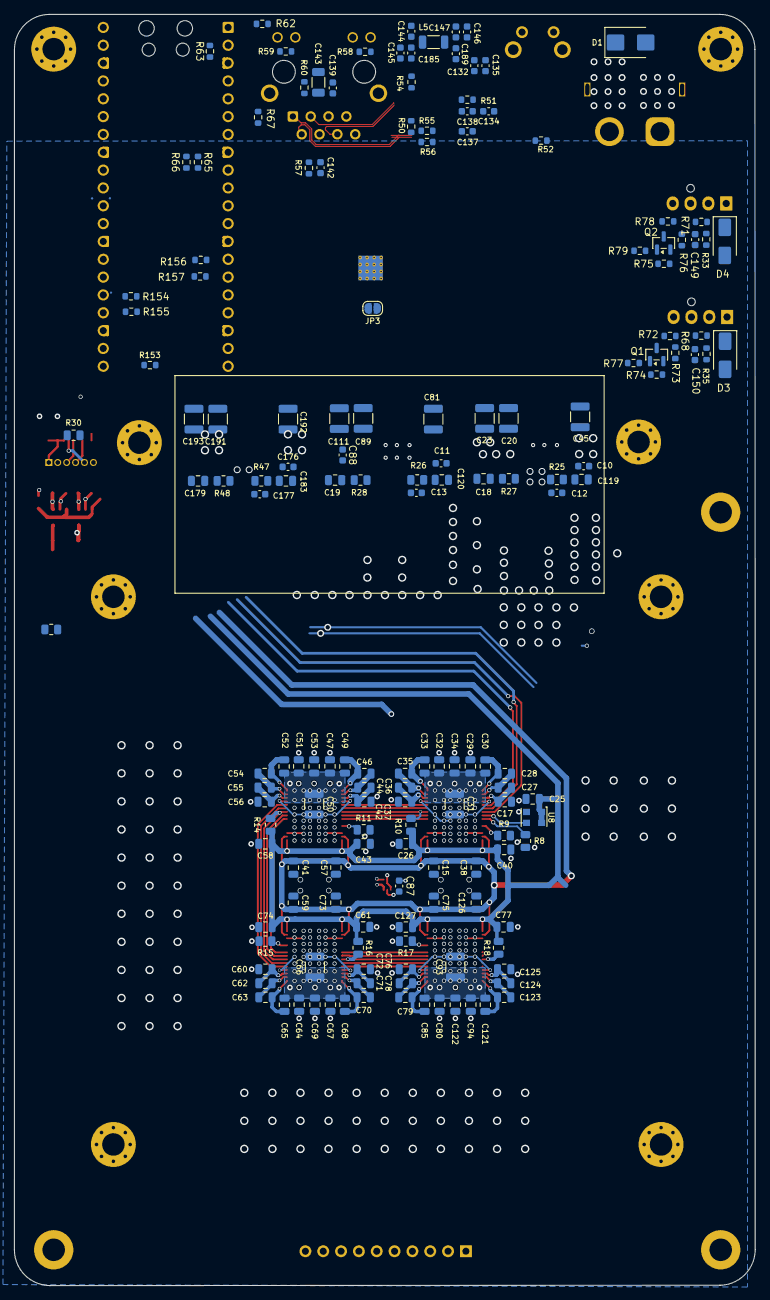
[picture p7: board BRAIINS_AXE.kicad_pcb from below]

Board: 6 copper layers, 105.5 x 181.1 mm, 303 parts (161 on the bottom side), 172 nets.

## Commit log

2026-06-25 POWER IN, OVLO, IDEAL DIODE
    [power_in.kicad_sch]
2026-06-25 power in components to PCB
    [ctrl.kicad_sch]
2026-06-26 updated power stage placements
    [Asic0.kicad_sch, BM1368-1.kicad_sch, BM1368-2.kicad_sch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]
2026-06-26 power stage in place
    [BRAIINS_AXE.kicad_sch, CONTROL.kicad_sch, bm1366.kicad_sch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]
2026-06-26 shrinking layout to fit
    [BRAIINS_AXE.kicad_sch, CONTROL.kicad_sch, FP1006V2-R.STEP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]
2026-06-26 optimizing pwr stage placement
    [power.kicad_sch]
2026-06-26 DC stage close to LGA socket
    [power.kicad_sch]
2026-06-26 3v3 eth
    [BRAIINS_AXE.kicad_pcb, CONTROL.kicad_sch]
2026-06-27 minor updates
    [BRAIINS_AXE.kicad_pcb]
2026-06-27 rp2350 module in place
    [BRAIINS_AXE.kicad_pcb]
2026-06-27 placing W5500
    [BRAIINS_AXE.kicad_pcb, BRAIINS_AXE.kicad_sch, CONTROL.kicad_sch]
2026-06-27 w5500 placed
    [BRAIINS_AXE.kicad_pcb, CONTROL.kicad_sch]
2026-06-27 updated to LGA1700
    [BRAIINS_AXE.kicad_pcb]
2026-06-27 rp2350 connections
    [BRAIINS_AXE.kicad_pcb, CONTROL.kicad_sch]
2026-06-27 sch_ should be ready
    [BRAIINS_AXE.kicad_pcb, CONTROL.kicad_sch, power.kicad_sch]
2026-06-27 controller resitors in place
    [BRAIINS_AXE.kicad_pcb]
2026-06-27 all components placed
    [BRAIINS_AXE.kicad_pcb]
2026-06-28 W5500 ROUTED
    [CONTROL.kicad_sch]
2026-06-28 logic dc bucks routed
    [CONTROL.kicad_sch]
2026-06-28 almost routed
    [BM1368-1.kicad_sch, BM1368-2.kicad_sch, BM1368-3.kicad_sch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]
2026-06-28 4mm NPTH mounting holes
    [BRAIINS_AXE.kicad_sch]
2026-06-29 Add clearence for heatsing
2026-06-29 Change micro symbol to uF
    [Asic0.kicad_sch, CONTROL.kicad_sch, power.kicad_sch]
2026-06-29 Add GND polygon to in4 layer
2026-06-29 Add schottky diode to rp pico vbus
    [CONTROL.kicad_sch, power.kicad_sch]
2026-06-30 Add LCSC number to components
    [Asic0.kicad_sch, BRAIINS_AXE.kicad_sch, CONTROL.kicad_sch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]
2026-06-30 Better 5V polygon connection
2026-06-30 Add missing LCSC number
    [power.kicad_sch]
2026-06-30 Use only stock component and unified LCSC capacitor code
    [Asic0.kicad_sch, CONTROL.kicad_sch, bm1366.kicad_sch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]
2026-07-01 5V header connectot added
    [CONTROL.kicad_sch, power.kicad_sch]
2026-07-01 Display connector is now PinSocket
    [CONTROL.kicad_sch, power.kicad_sch]
2026-07-01 A RGB connector added
    [CONTROL.kicad_sch, power.kicad_sch]
2026-07-01 V1.0.0 sample order ready
2026-07-01 v1.0:0 PCB samples in JLCPCB cart
